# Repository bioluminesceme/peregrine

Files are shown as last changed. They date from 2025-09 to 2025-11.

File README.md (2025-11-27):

# Peregrine Split Steno Keyboard 



A wired, split, handwired stenography keyboard with low profile Choc keys (close together to make hitting multiple keys at once easier/more comfortable)

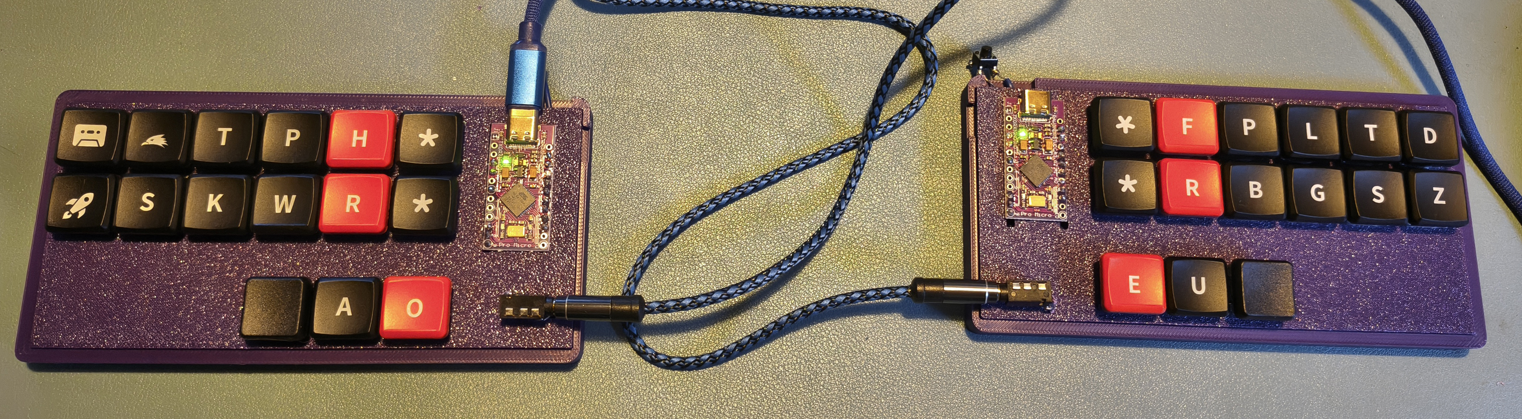
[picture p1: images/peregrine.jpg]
Peregrine v1

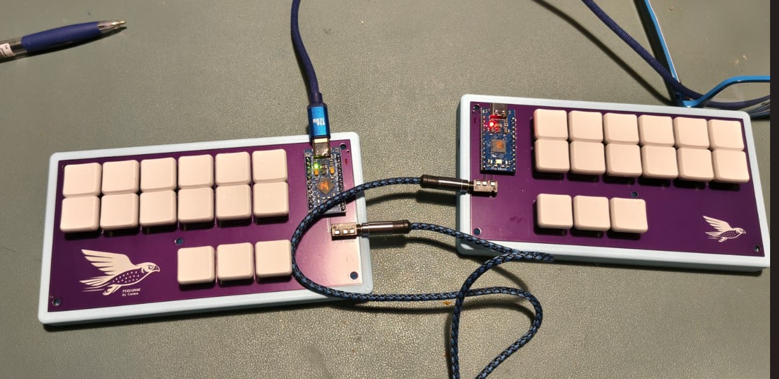
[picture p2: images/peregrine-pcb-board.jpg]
Peregrine with PCB boards


- [ ] (to add, Javelin version photo, green case, when done)

## Keymap layout

This keyboard has the default steno keyboard layout, but to make my life easier I have added 2 extra keys to the left half. This way both halves are symmetrical.
The extra keys are assigned to COPY and PASTE by default.

You can assign this to different keys in keymap.c (replace LCTL(KC_C) and LCTL(KC_V)) and then rebuild the firmware.

```txt
 ┌───┬───┬───┬───┬───┬───┐       ┌───┬───┬───┬───┬───┬───┐
 │CPY│ S │ T │ P │ H │ * │       │ * │ F │ P │ L │ T │ D │
 ├───┼───┼───┼───┼───┼───┤       ├───┼───┼───┼───┼───┼───┤
 │PST│ S │ K │ W │ R │ * │       │ * │ R │ B │ G │ S │ Z │
 └───┴───┴───┼───┼───┼───┤       ├───┼───┼───┴───┴───┴───┘
             │N1 │ A │ O │       │ E │ U │N2 │
             └───┴───┴───┘       └───┴───┴───┘

```

------

# Free files!

All the files are free, and come with beginner-friendly instructions.

You have the option to 

- [handwire](00handwire/HANDWIRE-INSTRUCTIONS.md)
- [use PCBS](00pcbs/PCB-SURFACEMOUNT-INSTRUCTIONS.md)

Handwiring is the cheapest option.

------

# Working on
- [x] Make a proper board in KiCAD (with thanks to the helpers in discord!) 
- [x] boards ordered 
- [x] board tested (and working!)
- [ ] Javelin (wish me luck)

------

# Will I sell this?
- No. I have no plans for a shop.
- I will have spare PCBs that I'm happy to sell so you don't have to order the minimum quantity (2x5) PCBS. If I do, I'll list them here. 
- I may have enough parts to sell a handful of presoldered boards (you add the Choc switches and keycaps). If I do, I'll list them here.
- First come first serve.
- I'm in the Netherlands so shipping might make this option quite expensive for some people compared to ordering them yourself
- Hand wiring is still a good option, and the cheapest way to make one.

# Can you sell this?
- Yes! 
- This repo has everything you need to make your own. 
- Just pay me 10 percent of your profits after the costs of the parts (not labor), for each sale.
- If you create a wireless version please let me add those files and instructions to this repo.



*20% of donations will go to MECFS Research by https://www.omf.ngo*

------

## HELP!

- Sorry, I will not be providing any technical support.

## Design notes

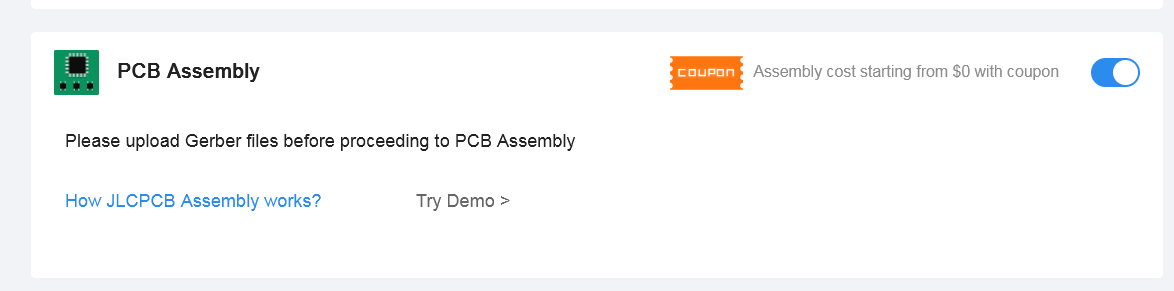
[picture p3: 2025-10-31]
images/jlc2.png

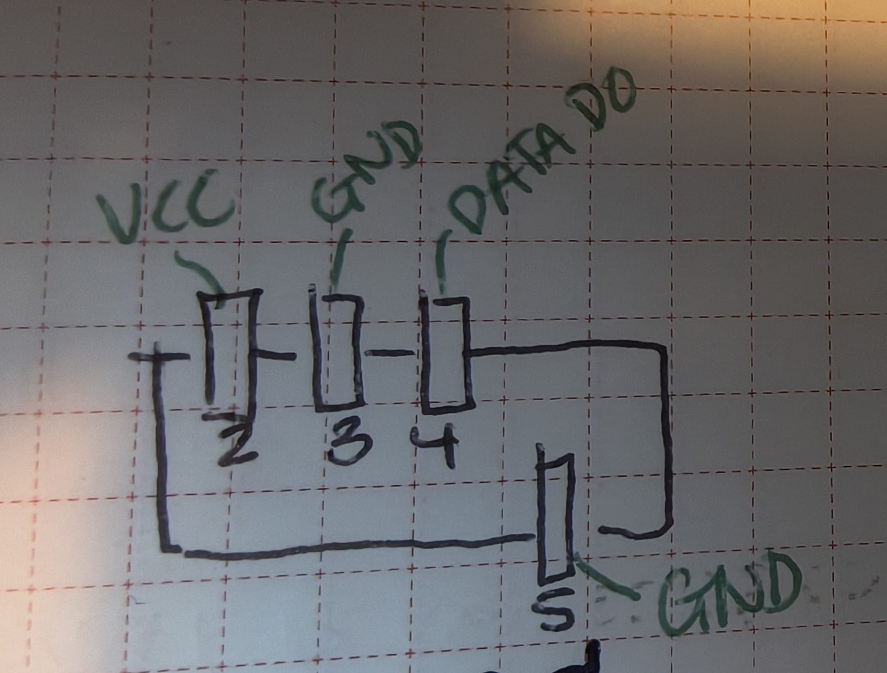
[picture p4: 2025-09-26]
images/trrs.jpg

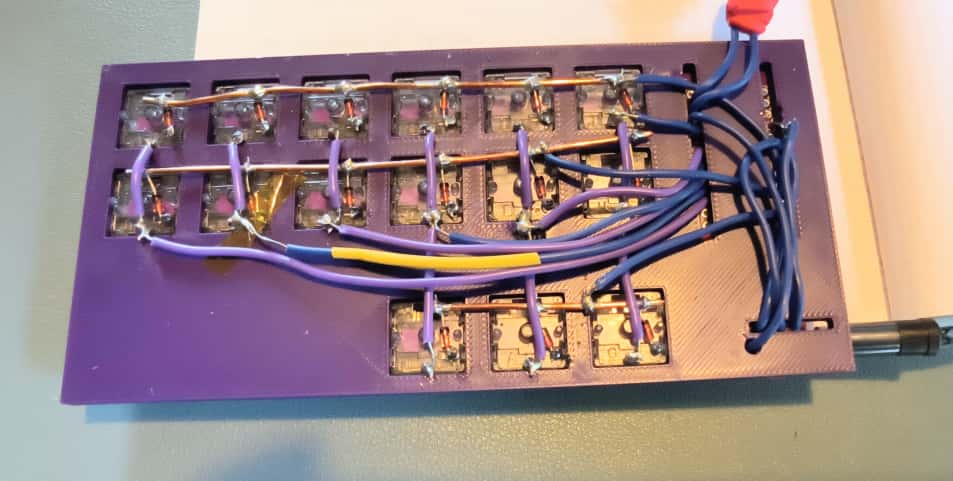
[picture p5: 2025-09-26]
images/tocontroller.jpg

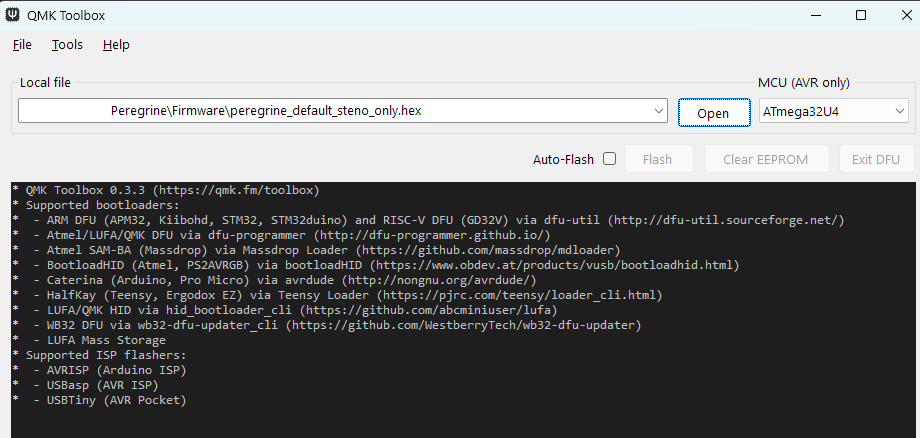
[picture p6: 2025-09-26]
images/qmktoolbox.jpg

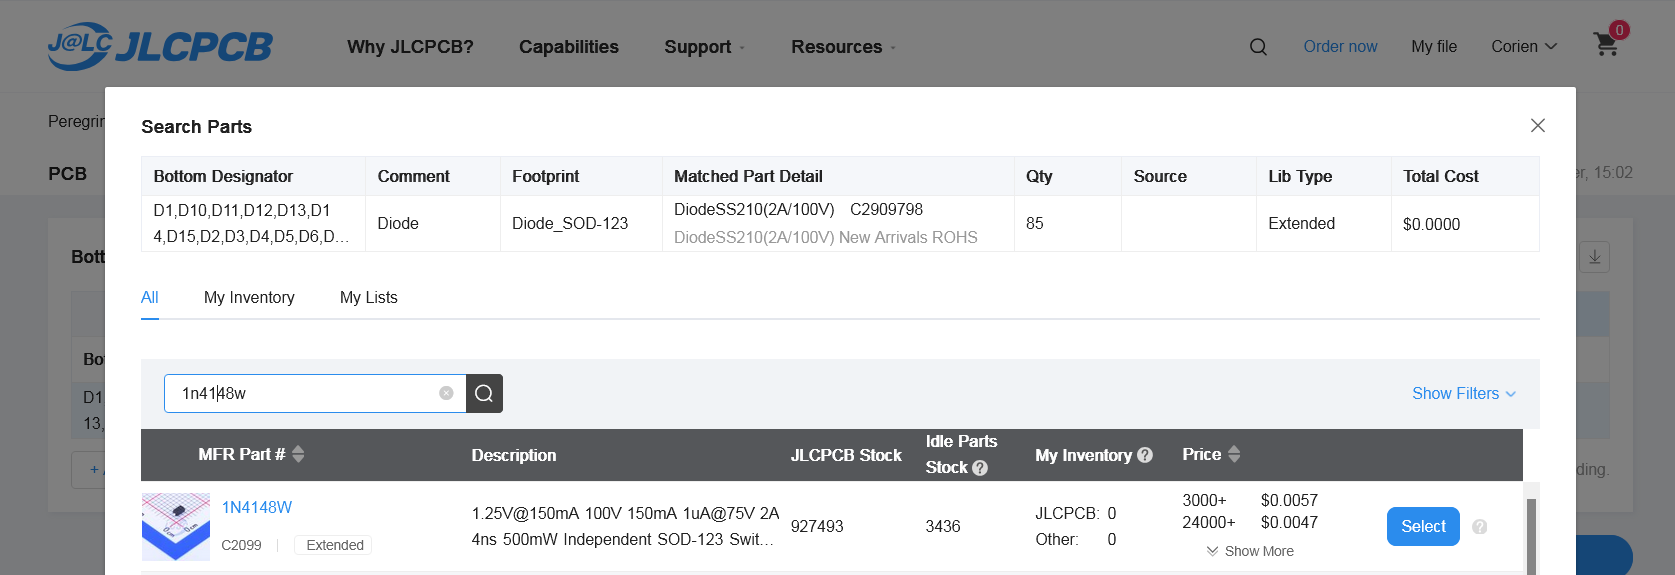
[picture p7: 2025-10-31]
images/jlc5.png

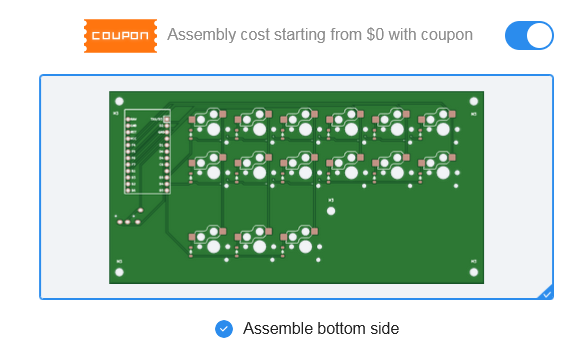
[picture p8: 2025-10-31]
images/jlc3.png

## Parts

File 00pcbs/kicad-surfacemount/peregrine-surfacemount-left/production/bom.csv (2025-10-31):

Designator | Footprint | Quantity | Value | LCSC Part #
D1, D10, D11, D12, D13, D14, D15, D2, D3, D4, D5, D6, D7, D8, D9 | Diode_SOD-123 | 15 | Diode
S1, S10, S11, S12, S13, S14, S15, S2, S3, S4, S5, S6, S7, S8, S9 | Hotswap_Choc_V1V2_1.00u | 15 | Keyswitch
U1 | Arduino_Pro_Micro | 1 | Arduino_Pro_Micro
U2 | TRRS_PJ-320A | 1 | TRRS

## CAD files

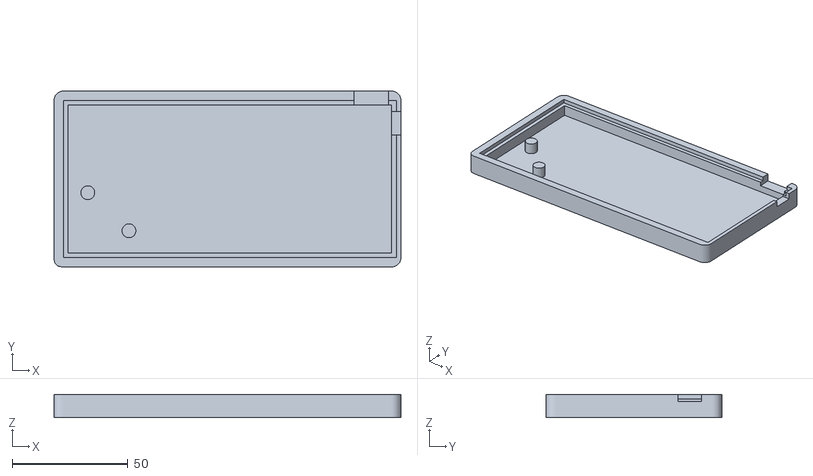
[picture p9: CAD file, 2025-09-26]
00handwire/3dmodels/case/peregrinechocleftside-8-10-case v4.stl
150.0 x 76.0 x 10.0

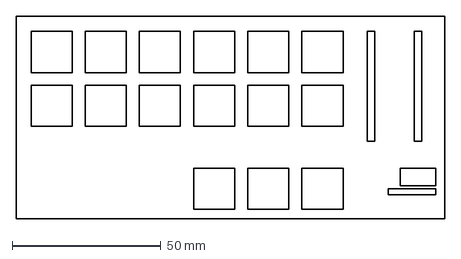
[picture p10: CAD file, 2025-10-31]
00handwire/3dmodels/switchplate/PeregrineLefty.dxf
144.0 x 68.0 mm

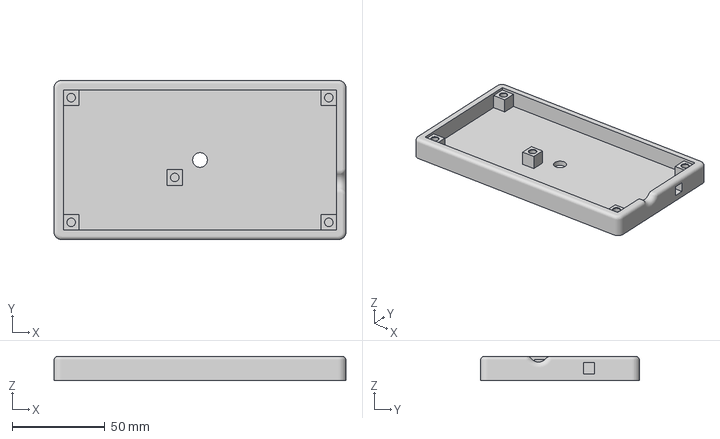
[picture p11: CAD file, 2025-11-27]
00pcbs/3dmodels/peregrine-surfacemount-left-case-with-tripodmount-and-TRRS-groove.3mf
157.0 x 85.5 x 13.0 mm

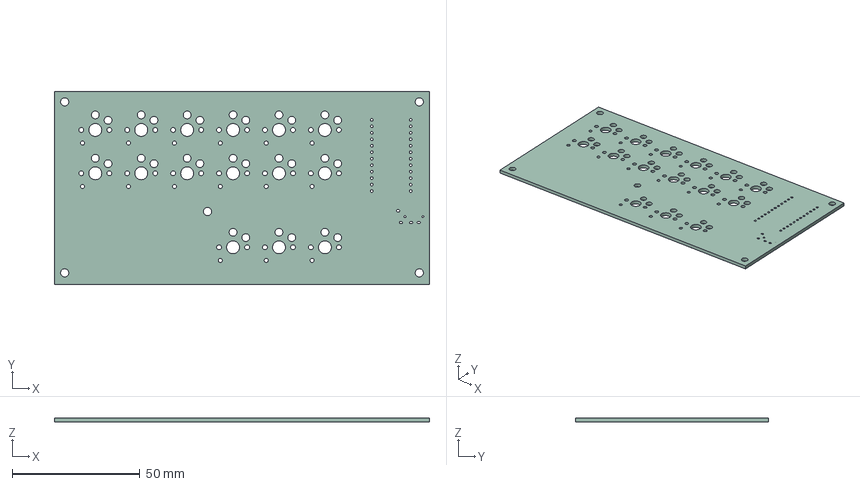
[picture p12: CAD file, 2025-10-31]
00pcbs/kicad-surfacemount/peregrine-surfacemount-left/peregrine-surfacemount-left-board.step
147.0 x 75.5 x 1.60 mm

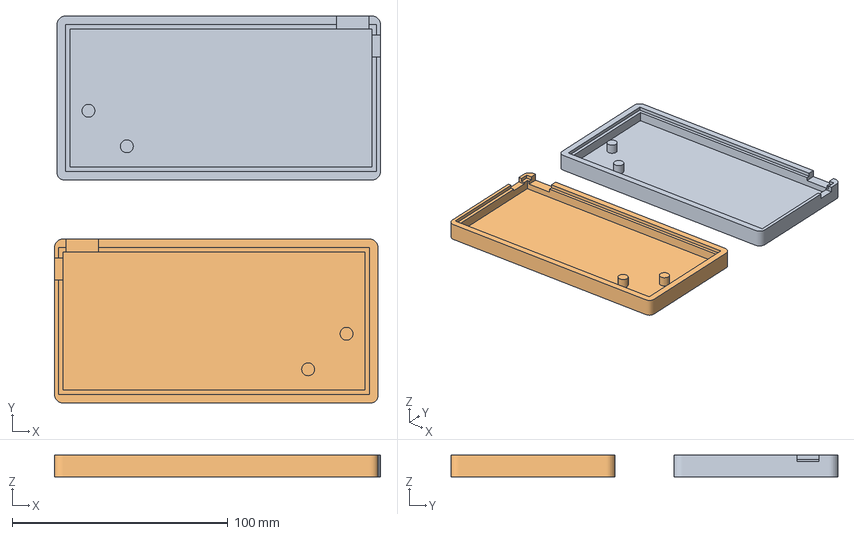
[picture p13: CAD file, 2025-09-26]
00handwire/3dmodels/case/peregrinechocleftside-8-10-casebothsides.3mf
151.1 x 179.4 x 10.0 mm
peregrinechocleftside-8-10-case v4.stl x 2

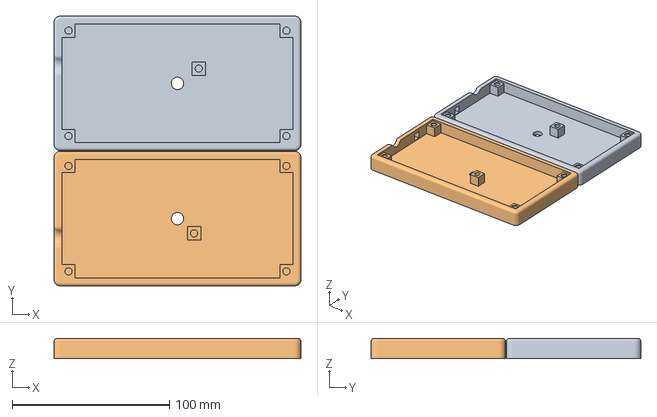
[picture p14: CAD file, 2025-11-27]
00pcbs/3dmodels/00BAMBUFILE-peregrine-green-cases-trsscutout-tripodhole.3mf
157.0 x 171.5 x 13.0 mm
rightcassegoed

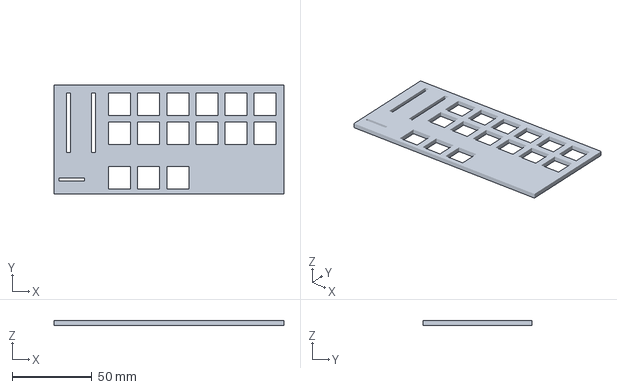
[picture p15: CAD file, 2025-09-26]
00handwire/3dmodels/switchplate/PeregrineChocPlateTighter v5-2.3mf
144.0 x 68.0 x 3.00 mm

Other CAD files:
00pcbs/kicad-surfacemount/peregrine-surfacemount-right/rightPCB.3mf
00handwire/3dmodels/switchplate/PeregrineChocPlateTighter v6.dwg
00pcbs/3dmodels/peregrine-surfacemount-right-case-with-tripodmount-and-TRRS-groove.3mf
00pcbs/3dmodels/peregrine-surfacemount-left-case-with-tripodmount-and-TRRS-groove.f3d
00pcbs/3dmodels/peregrine-surfacemount-right-case-with-tripodmount-and-TRRS-groove.f3d

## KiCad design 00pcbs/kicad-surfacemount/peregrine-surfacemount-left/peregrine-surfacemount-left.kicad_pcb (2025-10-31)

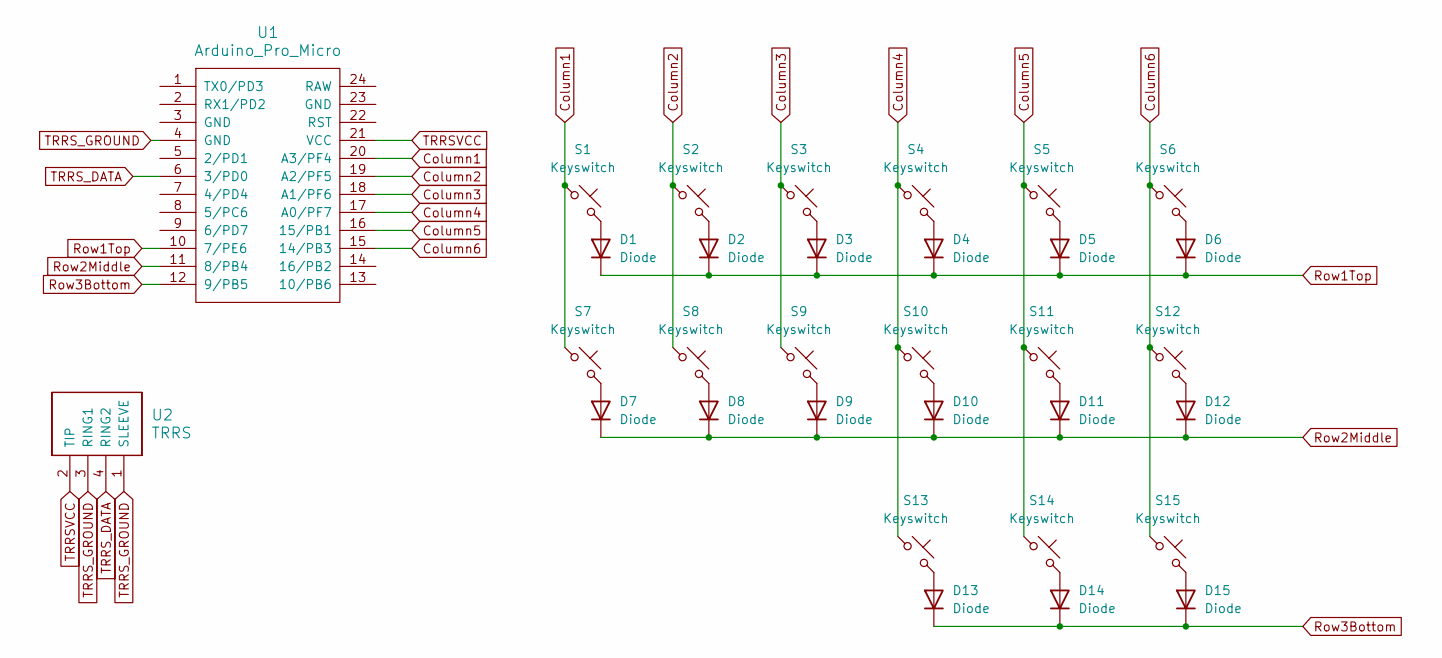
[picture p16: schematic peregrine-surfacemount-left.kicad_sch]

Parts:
D1, D2, D3, D4, D5, D6, D7, D8, D9, D10, D11, D12, D13, D14, D15: Diode; Diode_SOD-123
S1, S2, S3, S4, S5, S6, S7, S8, S9, S10, S11, S12, S13, S14, S15: Keyswitch; Hotswap_Choc_V1V2_1.00u
U1: Arduino_Pro_Micro
U2: TRRS; TRRS_PJ-320A

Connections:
Column1: S1.1, S7.1, U1.20 (A3/PF4)
Column2: S2.1, S8.1, U1.19 (A2/PF5)
Column3: S3.1, S9.1, U1.18 (A1/PF6)
Column4: S4.1, S10.1, S13.1, U1.17 (A0/PF7)
Column5: S5.1, S11.1, S14.1, U1.16 (15/PB1)
Column6: S6.1, S12.1, S15.1, U1.15 (14/PB3)
unnamed: D1.2 (A), S1.2
unnamed: D2.2 (A), S2.2
unnamed: D3.2 (A), S3.2
unnamed: D4.2 (A), S4.2
unnamed: D5.2 (A), S5.2
unnamed: D6.2 (A), S6.2
unnamed: D7.2 (A), S7.2
unnamed: D8.2 (A), S8.2
unnamed: D9.2 (A), S9.2
unnamed: D10.2 (A), S10.2
unnamed: D11.2 (A), S11.2
unnamed: D12.2 (A), S12.2
unnamed: D13.2 (A), S13.2
unnamed: D14.2 (A), S14.2
unnamed: D15.2 (A), S15.2
Row1Top: D1.1 (K), D2.1 (K), D3.1 (K), D4.1 (K), D5.1 (K), D6.1 (K), U1.10 (7/PE6)
Row2Middle: D7.1 (K), D8.1 (K), D9.1 (K), D10.1 (K), D11.1 (K), D12.1 (K), U1.11 (8/PB4)
Row3Bottom: D13.1 (K), D14.1 (K), D15.1 (K), U1.12 (9/PB5)
TRRSVCC: U1.21 (VCC), U2.2 (TIP)
TRRS_DATA: U1.6 (3/PD0), U2.4 (RING2)
TRRS_GROUND: U1.4 (GND), U2.1 (SLEEVE), U2.3 (RING1)

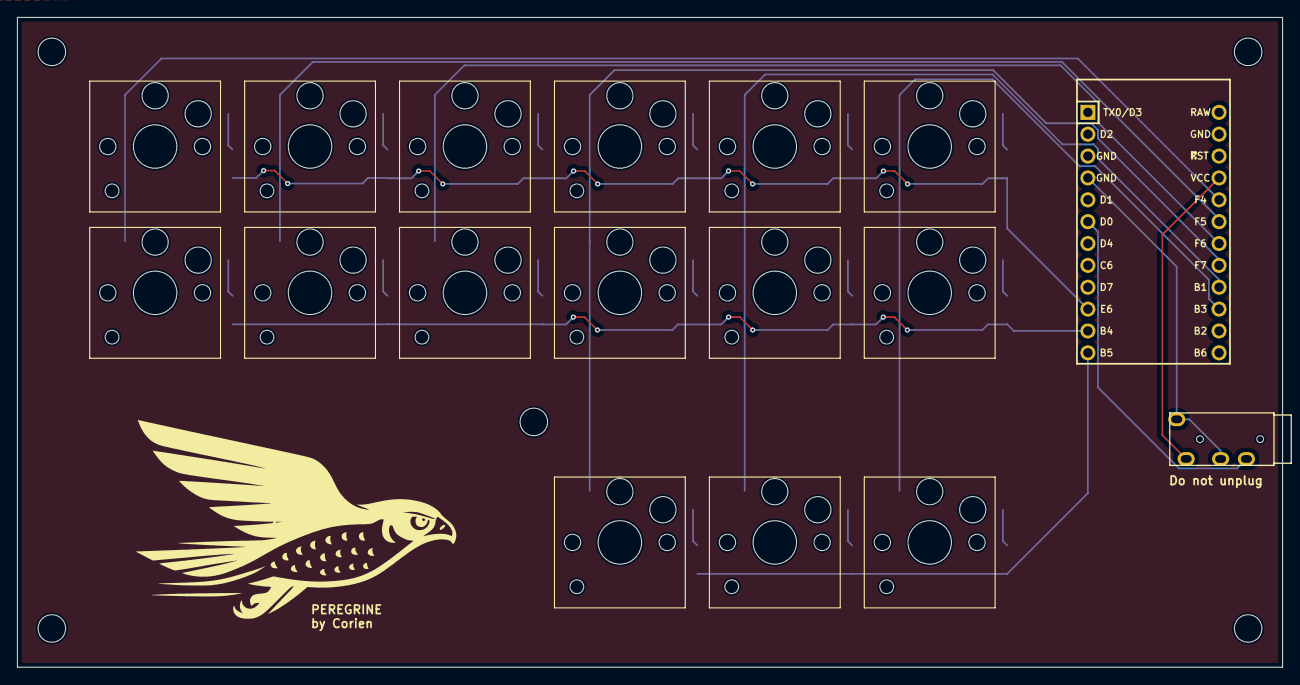
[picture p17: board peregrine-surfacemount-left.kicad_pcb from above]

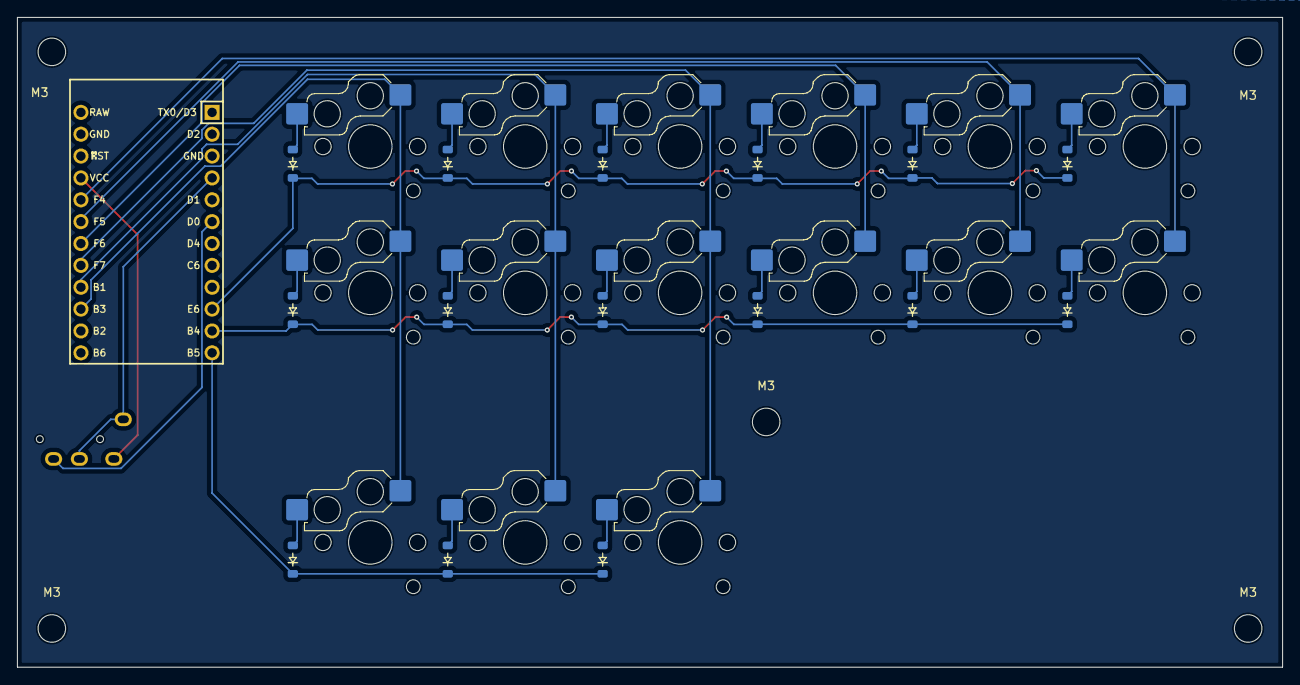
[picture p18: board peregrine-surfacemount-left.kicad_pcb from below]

Board: 2 copper layers, 147.0 x 75.5 mm, 37 parts (15 on the bottom side), 27 nets.

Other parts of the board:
M3, M3#2, M3#3, M3#4, M3#5: MountingHole_3.2mm_M3

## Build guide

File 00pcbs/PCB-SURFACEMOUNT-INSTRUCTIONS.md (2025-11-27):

Peregrine with PCB boards

# Ordering the board 

I recommend JLCPCB, and I highly recommend you order this so that **they** will solder those tiny surface mount diodes for you.
(if you're over 40, soldering those is not a very enjoyable experience)

This will cost about $90 shipped for 2 sets of 5 (5 right halves, 5 left halves), so about $18 per full keyboard in PCB costs (including shipping and them soldering the tiny things on).

- [ ] ToDo Add screenshots

# Soldering

- Solder on the surface mounted Choc hotswap sockets. Pretin the pads, put the part on top and either touch the solder on the pad with the edge of your soldering iron so it melts, or heat the leg of the socket until the solder melts -- gently push on the socket with something that won't burn your fingers until that side is flush with the surface. Repeat for the other side.
- TRSS, solder in the connector
- Install the firmware on the microcontroller first! This way you can check that the microcontroller is working (LED comes on and your PC dings when you connect it, and firmware installation succeeds). Then solder in the microcontroller pin things that come with it, then solder the microcontroller to that. 

- then push the 2 metal legs of your choc switches into the socket holes
- and add some keycaps

- connect the TRRS cable between both halves first.
- then plug the board in, start Plover and type away!

- [ ] ToDo Add photos

## Case

- The 3D files are in 00PCBsurfacemount\3dmodels this includes the ready to print 3mf, and a f3d autodesk fusion file that I hope will let people make easy changes
- There are 5 heatset holes for if you want to screw the board to the case, but honestly the friction fit is tight and more than enough to keep the board in place
- There is a hole in the bottom of the case for a 1/4-20 brass heatset thing so you can mount the board to a tripod/chair/whatever.
- hotglue the reset button in place so that you can press it through the hole, but also so it does not stick out and gets pressed accidentally. (you will only need it to flash firmware)
- Tested with a Bambu A1 on default/factory settings with light blue and light green Bambu matte filament. No issues at all.

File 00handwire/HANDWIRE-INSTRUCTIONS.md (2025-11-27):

# Peregrine Split Steno Keyboard 



A wired, split, handwired stenography keyboard with low profile Choc keys (close together to make hitting multiple keys at once easier/more comfortable)

The left half is set to master, this means the USB cable that connects the keyboard to your computer has to be connected to the left half. You can change it to MASTER_RIGHT in qmk_firmware\keyboards\peregrine\config.h and then recompile the firmware.

! Important.
Never pull the TRRS cable out when the keyboard is connected. (apparently this can short everything)

Peregrine v1

## Keymap layout

This keyboard has the default steno keyboard layout, but to make life easy I have added 2 extra keys to the left half. This way both halves are symmetrical.
The extra keys are assigned to COPY and PASTE respectively.

You can assign this to different keys in keymap.c (replace LCTL(KC_C) and LCTL(KC_V))
and then rebuild the firmware.

```txt
 ┌───┬───┬───┬───┬───┬───┐       ┌───┬───┬───┬───┬───┬───┐
 │CPY│ # │ T │ P │ H │ * │       │ * │ F │ P │ L │ T │ D │
 ├───┼───┼───┼───┼───┼───┤       ├───┼───┼───┼───┼───┼───┤
 │PST│ S │ K │ W │ R │ * │       │ * │ R │ B │ G │ S │ Z │
 └───┴───┴───┼───┼───┼───┤       ├───┼───┼───┴───┴───┴───┘
             │N1 │ A │ O │       │ E │ U │N2 │
             └───┴───┴───┘       └───┴───┴───┘

```

Small note: I couldn't get the top Steno S1 key to work, it is assigned S1, but outputs #. The bottom S one works though, use that.
Edit - I think this is because of a setting in Plover where you can set the key to # or S!

This is a guide for people who have never soldered a thing before.
Expect soldering to take about a day.

## Parts List

- 30x Choc switches (I used purple ones from [aliexpress](https://www.aliexpress.com/item/1005005883472162.html?spm=a2g0o.order_list.order_list_main.100.1ed918024ECzr8) ) 25grams )
- 30x keycaps (3D printed, see in 3dmodels folder, or you can buy pretty custom ones from https://fkcaps.com/ )
- 30x 1N4148 DO-35 through-hole diodes (I got them on [aliexpress](https://www.aliexpress.com/item/4000142272546.html?spm=a2g0o.order_list.order_list_main.50.1ed918024ECzr8) in a pack of 100  )
- bare copper wire 16 AWG (1.25mm bought locally)
- solid/single core insulated wire (I got purple, 22AWG, 20meters on [aliexpress](https://www.aliexpress.com/item/1005004336218242.html?spm=a2g0o.order_list.order_list_main.20.1ed918024ECzr8) )
  - you can use both or either of these wires to solder with. The bare copper wire is easy to work with and gives some support to the switches, but you can't make any other metal touch it so I used the insulated wire for the columns.
- 2x ATMega32U4 ProMicro compatible microcontroller with USB-C connector [aliexpress](https://www.aliexpress.com/item/1005006322199481.html?spm=a2g0o.order_list.order_list_main.60.1ed918024ECzr8)
- 2x TRRS jack (3.5mm 4-pole) [per half](https://www.aliexpress.com/item/33029465106.html?spm=a2g0o.order_list.order_list_main.75.1ed918024ECzr8)   
- 2x Reset button (6x6x6 mm tactile switch, [aliexpress](https://www.aliexpress.com/item/1005006195785196.html?spm=a2g0o.order_list.order_list_main.170.1ed918024ECzr8) )
- 1x TRRS cable to connect halves [aliexpress](https://www.aliexpress.com/store/4662071?spm=a2g0o.order_list.order_list_main.177.1ed918024ECzr8) 
- 1x USB-C cable - connect this to the *left* half always, and connect that to the PC. [aliexpress](https://www.aliexpress.com/item/1005006620224278.html?spm=a2g0o.order_list.order_list_main.202.1ed918024ECzr8)
- wire stripper (to remove part of the insulation of the insulateded wire)
- wire cutter
- pliers to bend the wire into a loop for soldering

## 3D printed switch plate and case
  - switch plate: I forgot a hole for the last connection pin of the TRRS connector. Drill a small hole for that.
  - the case has some extra spacing on the side in case you want to mount the microcontroller on the bottom of the switchplate.
  - it also has some supporting pins. they were in the way of my wiring so I snipped those off.

# Start here

https://geekhack.org/index.php?topic=87689.0

Read this excellent hand soldering guide.

# What thing should be connected to which hole ?!

Microcrontroller types have different hole numbers. This is confusing and annoying.

hole number guide

For example as you can read below, column 3 on the left half (the column  that connects the T and K keys into a column) should be wired to P19 - Pin 19 - which on the atmega32u4 is marked A1 

## Left Half Pin Assignments  

### Column Pins  
- Column 1 (COPY, PASTE): P21   (A3)
- Column 2 (S, S): P20  (A2)
- Column 3 (T, K): P19   (A1)
- Column 4 (P, W, STN_N1): P18  (A0)
- Column 5 (H, R, A): P15   (15)
- Column 6 (*, *, O): P14   (14)

### Row Pins 
- Row 1 (Top): P7   (7)
- Row 2 (Middle): P8   (8)
- Row 3 (Bottom): P9   (9)

## Right Half Pin Assignments  

### Column Pins  
- Column 1 (*, *, E): P21 (A3)
- Column 2 (F, R, U): P20 (A2)
- Column 3 (P, B, STN_N2): P19 (A1)
- Column 4 (L, G): P18 (A0)
- Column 5 (T, S): P15 (15)
- Column 6 (D, Z): P14 (14)

### Row Pins  
- Row 1 (Top): P7 (7)
- Row 2 (Middle): P8 (8)
- Row 3 (Bottom): P9 (9)

## Diode Orientation (Column to Row)

- Diodes prevent ghosting in matrix
- **Anode** side is the positive end, this does **not** have the black band. It connects to metal pin on the **Choc switch**
- **Cathode** side is the negative end, this has the **black band**. This leg connects to the **row wire**

## Handwiring Steps

### For Each Half:

1. **Prepare switches**
   - Push the Choc switches in the switch plate, this should be a snug fit.
   
2. **Install diodes, add row wire**
   - Bend a small loop in the diode leg as per the guide I linked to. (do this in the diode leg end that does *not* have the black stripe)
   - Put the loop around the switch pin and solder it.
   - Lay the copper wire down across the row, loop all the diode legs that *do* have the black stripe around the wire with some pliers/tweezers, and solder those.
   - The rows are now soldered!
  
   rows done

3. **Add column wires**
   - Cut the insulated wire to a bit longer than you think you need and loop the ends.
   - put the end loops around the remaining pins on the Choc switches to connect them
   - Solder the column wires

   columns done

4. **Solder everything to the microcontroler**
   - You can and probably should flash it first, to make sure the board is not defective, before you solder it on.
   - You can also use mounting pins to make it easy to replace the board when it breaks. 
   - I did not do any of this.
   - Carefully look at what row/column wire should be connected to which pin. 
   - You can solder from any point on the row/column (from any part of the exposed wire, or from any Choc pin) to the pin/hole on the microcontroller. 
   - (ignore the yellow heat shrink tubing, I had stripped a bit too much off that wire and planned to heatshrink it to fix that, but the wire got hot enough from my soldering that the heatshrink contracted.)

   soldering done
  
5. With a multimeter, set it to the sound symbol so it will beep, and check with the probes that all your rows and columns are indeed connected to the pin on the microcontroller. Or skip this step and see if the board has any keys on 1 row or 1 column that do not work, in which case there's a connection that needs to be fixed.
It's easy to lift the plate out of the case. 

6. **Add the TRRS connectors**
   - Tip=VCC, Ring1=GND, Ring2=Data (pin D0), Sleeve=GND
   - Tip is the tip of the plug, sleeve is closest to the cable.
   - Tip is inserted into the connector, so it's the 'farthest away' pin.
   - Connect Data (Ring2) to pin D0 on both halves
   - Connect VCC (Tip) to VCC on both halves
   - Connect GND (Ring1 and Sleeve) to GND on both halves
   - I found several wiring options for TRRS on different boards, so I'm not sure this actually matters too much, as long as both TRRS jacks are wired the exact same way and have GND, VCC and Data, and the Data pin D0 is set correctly in qmk_firmware\keyboards\peregrine\keyboard.json?
 
7. **Add the reset buttons**
   - The reset button is a rectangle.
   - The pins on the short side of the rectangle are GND(ground) and RST (reset)
   - Does not matter which way around.
   - The reset button is used to enter bootloader mode
   - Update. I may remove these reset buttons and go with boot magic in the firmware only, or at least hide the reset buttons somewhere inside the case (to prevent accidentally clicking them), and to make the board look better. I had expected to need to reset my first version quite often. But I've not needed to do this after the first time I flashed the firmware. 

```
      ┌───────────┐
 [GND]│           │[GND]
 [RST]│           │[RST]
      └───────────┘

```
 
# ** Flashing the Firmware**
   - Download [QMK Toolbox](https://qmk.fm/toolbox)
   - Open the firmware you want in the Toolbox, choice between left/right side is master (master is the side that you connect to your PC with a USB cable)
   - firmware\F:\Keyboards\PeregrineGithub\firmware\QMK\peregrine_master_left_promicro_atmega32u4.hex
   - firmware\F:\Keyboards\PeregrineGithub\firmware\QMK\peregrine_master_right_promicro_atmega32u4.hex
   - Connect one atmega32u4 microcontroller to your computer with a USB-C cable (you need to flash both microcontrollers individually, so repeat these steps for the other one). 
   - The microcontroller will show as **connected** in the Toolbox, and the Flash button will become enabled. Click it and wait a few seconds, it should show some kind of success message. 
   - Repeat for the other microcontroller

   QMK Toolbox
   
## Recompile the firmware

If you want to change anything, for example set the Copy and Paste keys to something different, you need change that in the code and recompile the firmware.
   -  Install QMK 
   -  copy the qmk_firmware folders into your qmk root folder 
   -  set user keyboard to peregrine
   -  `> qmk compile -kb peregrine -km default`
   -  firmware will compile into a new .hex file in the qmk root folder
   -  use the toolkit to flash it onto both microcontroller boards.
  
Happy typing!

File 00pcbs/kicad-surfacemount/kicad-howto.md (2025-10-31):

# If you want to order proper PCBs for this Peregrine keyboard.

There are 2 versions.

## Hotswap Choc with surface mount diodes

- Hotswap sockets for the Choc switches (solder on yourself)
- surface mount 1N4148W diodes. holy hell these things are small. I highly recommend you let JLCPBC solder these on (should cost about 19 dollars extra for 2x5 boards)

## Choc switches and through hole diodes
- standard Choc switches
- standard 1N4148 diodes with the legs and the stripe.

## Order as is
Go to JLCPCB.com (cheaper). Click Instant Quote, then click the upload Gerbers file and select the zip file in 
(peregrine - your choice - left / right / production)

For example for the left board of the surface mount, you'd upload 
kicad\peregrine-surfacemount-left\production\PeregrineKicadLeftSMDFinal.zip

JLC step 1
Pick the board color you want.

Enable PCB assembly 

And select "Assemble bottom side"


then click the big blue Next button in the right sidebar under the price.

Click next and it will ask you to upload the BOM and CPL file


Upload bom.csv to BOM, and positions.csv to CPL

It will then likely complain about a shortfall (lack of stock) for the diodes.
Click the magnifying glass to search for a replacement part, 
type in 

1n4148w in the field (for surface mount diodes)


And then get your quote and shipping etc.

# Change board layout

If you want to make changes to the spacing/components on the board.
Open KiCad 8.0 (9.0 has some compatibility problems)

File - open Project.
Navigate to one of the folders, for example kicad\peregrine-surfacemount-left
And it will let you open the project file.

Watch all of https://youtu.be/8WXpGTIbxlQ for an excellent walk through
and open the schematic file, and the corresponding board file

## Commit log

2025-09-26 Initial commit. Peregrine 2025
    [peregrinechocleftside-8-10-case v4.stl, peregrinechocleftside-8-10-casebothsides.3mf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]
2025-09-26 Added a photo of Peregrine assembled
2025-09-26 Added a ko-fi button ♥
2025-10-29 Revise ToDo section to Working and Future possibilities
    Updated the README to reflect current plans and future possibilities.
2025-10-31 Added KiCad files for 2 board versions. Surface mount hotswap / through hole Choc switches.
    [PeregrineLefty.dxf, bom.csv, designators.csv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]
2025-10-31 Added kicad howto, need to improve this later, test boards first.
2025-11-27 Updated ReadMe, added instructions, added 3D case files
    [PeregrineLefty.dxf, bom.csv, designators.csv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]
2025-11-27 added photo of finished PCB, cleaning up
    [00BAMBUFILE-peregrine-green-cases-trsscutout-tripodhole.3mf, bom.csv, designators.csv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]
